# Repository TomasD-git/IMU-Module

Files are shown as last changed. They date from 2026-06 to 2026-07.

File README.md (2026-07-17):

# IMU-Module  
Simple IMU module, uses LSM6DSOXTR as IMU and XC6228D332VR-G as LDO    
I made this because most IMU have some sort of fallback, either bad imu, no ldo on board etc.. 

<details>
  <summary>BOM</summary>
  
| Name|Purpose|Quantity|Total Cost (USD)|Link|Distributor |  
| ----|---|---|---|----|--- |
| PCB + stencil|all components are on this|5|8|https://jlcpcb.com|jlcpcb |  
| ALL components|all components that are on pcb|1|10|https://lcsc.com|lcsc|  
|  |  |  Total cost|38| | |  

</details>

In production folder, is lcsc bom which has all components ready to import to lcsc, and gerber files and placement if using pcba.  

# Pictures  

**Schematic**  
  
**PCB**  
  
**3D Viewer**


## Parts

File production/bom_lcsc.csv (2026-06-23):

Designator | Footprint | Quantity | Value | LCSC Part #
C1, C4, C6, C7 | 0402 | 4 | 100nF | C152814
C2, C5 | 0603 | 2 | 1uF | C519560
C3 | 0805 | 1 | 10uF | C5137471
J1 | PinHeader_1x06_P2.54mm_Vertical | 1 | Conn_01x06
R2 | 0603 | 1 | 100K | C2907088
R3, R4 | 0402 | 2 | 4.7K | C48392572
TP1 | SolderJumper-2_P1.3mm_Open_TrianglePad1.0x1.5mm | 1 | TestPoint_2Pole
U1 | LGA-14L_L3.0-W2.5-P0.50-TL | 1 | LSM6DSOXTR | C481766
U2 | SOT-25-5_L3.0-W1.8-P0.95-LS3.0-BR | 1 | XC6228D332VR-G | C69841

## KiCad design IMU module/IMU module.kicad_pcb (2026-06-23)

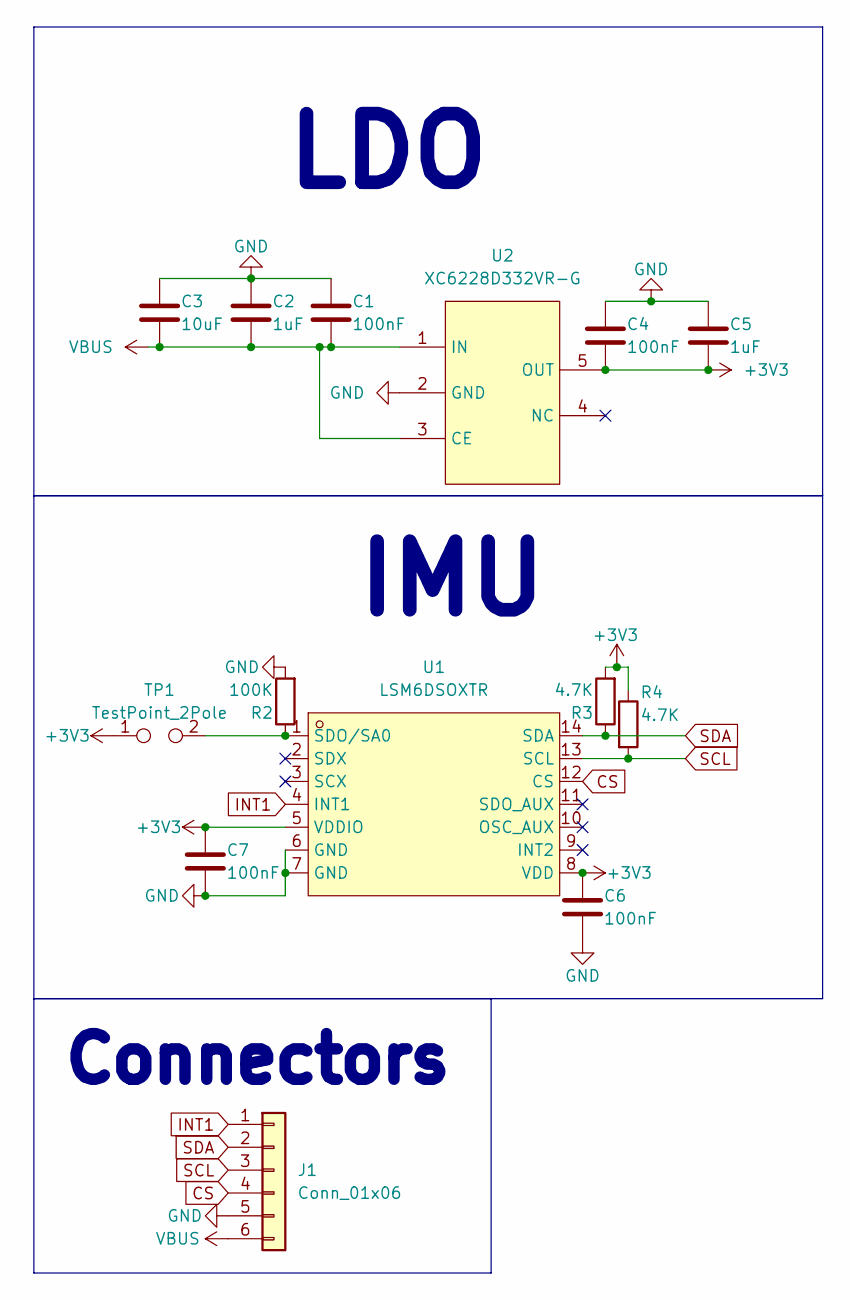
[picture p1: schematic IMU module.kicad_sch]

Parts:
C1, C4, C6, C7: 100nF; C_0402_1005Metric
C2, C5: 1uF; C_0603_1608Metric
C3: 10uF; C_0805_2012Metric
J1: Conn_01x06; PinHeader_1x06_P2.54mm_Vertical
R2: 100K; R_0603_1608Metric
R3, R4: 4.7K; R_0402_1005Metric
TP1: TestPoint_2Pole; SolderJumper-2_P1.3mm_Open_TrianglePad1.0x1.5mm
U1: LSM6DSOXTR; LGA-14L_L3.0-W2.5-P0.50-TL; MPN LSM6DSOXTR; LCSC Part C481766
U2: XC6228D332VR-G; SOT-25-5_L3.0-W1.8-P0.95-LS3.0-BR; MPN XC6228D332VR-G; LCSC Part C69841

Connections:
+3V3: C4.2, C5.2, C6.1, C7.1, R3.2, R4.1, TP1.1, U1.5 (VDDIO), U1.8 (VDD), U2.5 (OUT)
CS: J1.4, U1.12 (CS)
GND: C1.1, C2.1, C3.1, C4.1, C5.1, C6.2, C7.2, J1.5, R2.2, U1.6 (GND), U1.7 (GND), U2.2 (GND)
INT1: J1.1, U1.4 (INT1)
unnamed: R2.1, TP1.2, U1.1 (SDO/SA0)
SCL: J1.3, R4.2, U1.13 (SCL)
SDA: J1.2, R3.1, U1.14 (SDA)
VBUS: C1.2, C2.2, C3.2, J1.6, U2.1 (IN), U2.3 (CE)

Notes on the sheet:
LDO
Connectors
IMU

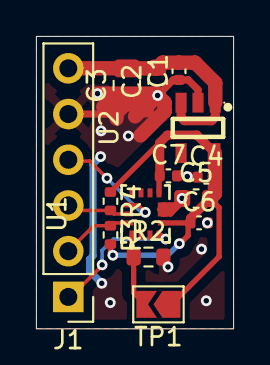
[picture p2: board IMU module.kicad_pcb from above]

Board: 2 copper layers, 11.0 x 16.2 mm, 14 parts (0 on the bottom side), 8 nets.

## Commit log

2026-07-17 Update BOM.csv with new quantities and costs
    [BOM.csv]
2026-07-17 Revise README with additional information
    Updated the description and BOM details in README.
2026-07-17 Rename project to IMU-Module and update description
    Updated project name and description in README.
